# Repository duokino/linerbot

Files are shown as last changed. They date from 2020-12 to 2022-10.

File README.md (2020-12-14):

# LinerBot
Idea asal LinerBot adalah membina sebuah mobile robot mini yang mampu mengesan dan bergerak mengikut garisan.

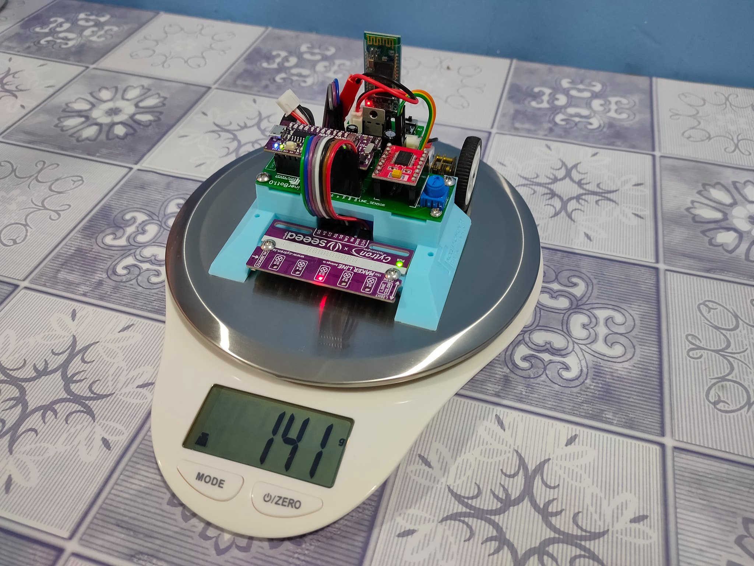
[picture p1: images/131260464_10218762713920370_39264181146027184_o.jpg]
LinerBot


Dalam proses membina LinerBot telah berlaku beberapa proses seperti ujian pendawaian motor, kalibrasi penjajaran roda kanan dan kiri dan beberapa proses lain bagi memastikan LinerBot dapat bergerak secara optimum.

Kesemua proses ini memerlukan komponen tambahan bagi memudahkan proses tersebut. Dari situ terhasil Papan Induk Kawalan LinerBot bagi memudahkan proses tersebut seperti keperluan kepada pengguna Push Button, Potentiometer dan terminal port yang lain yang boleh menambahkan fungsi LinerBot.

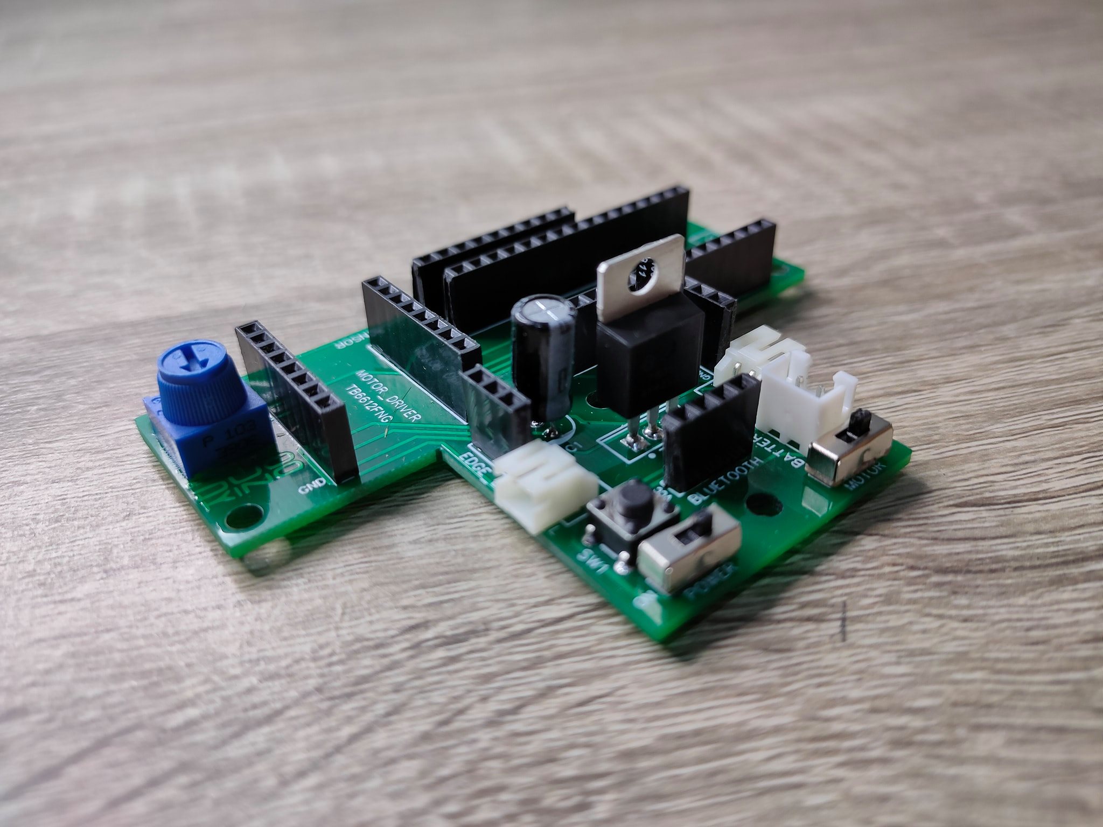
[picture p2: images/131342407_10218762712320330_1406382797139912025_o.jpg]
Additional Input/Output


Papan Induk Kawalan LinerBot ini sedikit sebanyak membantu proses pembelajaran khasnya dalam pembinaan mobile robot daripada asas kepada fungsi tambahan kawalan jarak jauh dan seterusnya fungsi autonomous.

Kawalan jarak jauh boleh menggunakan Bluetooth Module seperti HC-05 atau HC-06 menggunakan terminal Bluetooth yang tersedia pada Papan Induk Kawalan LinerBot.

Mode kawalan jarak jauh juga boleh menggunakan Remote Control seperti jenis Futaba dan yang seangkatan dengannya menggunakan terminal EDGE_L dan EDGE_R sebagai GPIO1 dan GPIO2 signal input. Ini menjadikan Linerbot boleh dikawal dengan alat kawalan radio frekuensi yang lebih advance.

Kesediaan terminal bagi sensor juga membolehkan LinerBot sama ada digunakan untuk robot yang bergerak mengikut garisan atau yang boleh mengelak objek malah boleh juga digunakan sebagai robot sumo.

Kepelbagaian ini semua adalah bergantung pada kreativiti programming yang dibuat yang sememangnya sesuai digunakan untuk tujuan pembelajaran mobile robot atau autonomous robot.

- Buzzer menggunakan D8
- Push Button menggunakan D2 (INPUT_PULLUP)
- Potentiometer/Trimmer menggunakan A0

Bahan untuk membina LinerBot :
  - Chassis (3D Printed main_body.stl)
  - M3 x 6mm self tapping screw

Komponen utama yang perlu dipasang pada Papan Induk Kawalan LinerBot ini adalah :
  - Arduino Nano (penggunaan Maker Nano akan menjadikannya lebih menarik)
    (https://my.cytron.io/p-maker-nano-simplifying-arduino-for-projects?search=maker&description=1)
  - Motor Driver TB6612FNG
    (https://my.cytron.io/p-tb6612fng-dual-channel-1p2a-motor-driver-presoldered-header?search=tb6612&description=1)
  - Metal Micro GearMotor (dicadangkan 6V 600rpm)
    (https://my.cytron.io/p-6v-600rpm-medium-power-dc-micro-metal-gearmotor)
  - LiPo Battery 7.4V
    (https://my.cytron.io/p-lipo-battery-7.4v-450mah)
  - Mini Wheel 34x7mm
    (https://my.cytron.io/p-mini-wheel-34x7mm-for-n20-gear-motor?search=wheel&description=1)

Untuk fungsi Bluetooth RC memerlukan komponen tambahan Bluetooth Module sama ada :
  - HC-05 atau HC-06

Untuk fungsi robot mengikut garisan :
  - Maker Line
    (https://my.cytron.io/p-maker-line-simplifying-line-sensor-for-beginner?search=maker%20line&description=1)
  atau
  - LSS05
    (https://my.cytron.io/p-auto-calibrating-line-sensor?search=lss05&description=1)
  tambahan
  - Maker Reflect
    (https://my.cytron.io/p-maker-reflect-simplifying-ir-reflectance-sensor-for-beginner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)

Untuk fungsi robot sumo atau robot pengelak objek dicadangkan menggunakan :
  - Maker Object
    (https://my.cytron.io/p-maker-object-simplifying-object-sensor-for-beginner?search=maker%20object&description=1)
  atau
  - HC-SR04 Ultrasonic Sensor
    (https://my.cytron.io/p-5v-hc-sr04-ultrasonic-sensor?search=ultrasonic&description=1)

Untuk fungsi RC Radio Frekuensi boleh menggunakan FlySky 3 Channels RC Radio Transmitter and Receiver dan yang seangkatan dengannya
(https://my.cytron.io/p-flysky-3-channels-rc-radio-transmitter-and-receiver)

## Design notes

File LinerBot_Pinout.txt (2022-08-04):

//*******PINOUT*******\\

Trimmer Pot	= A0

Analog Input	= A1
		= A2
		= A3
		= A4
		= A5

CAL		= 13

EDGE_L		= A6
EDGE_R		= A7

BUZZER		= 8

PushButton	= 2

PWMA		= 3
AIN1		= 5
AIN2		= 4

PWMB		= 10
BIN1		= 12
BIN2		= 11

Bluetooth_RX	= 0 (TX)
Bluetooth_TX	= 1 (RX)

//***Pin Not In Use***\\
	6 (PWM)
	7
	9 (PWM)

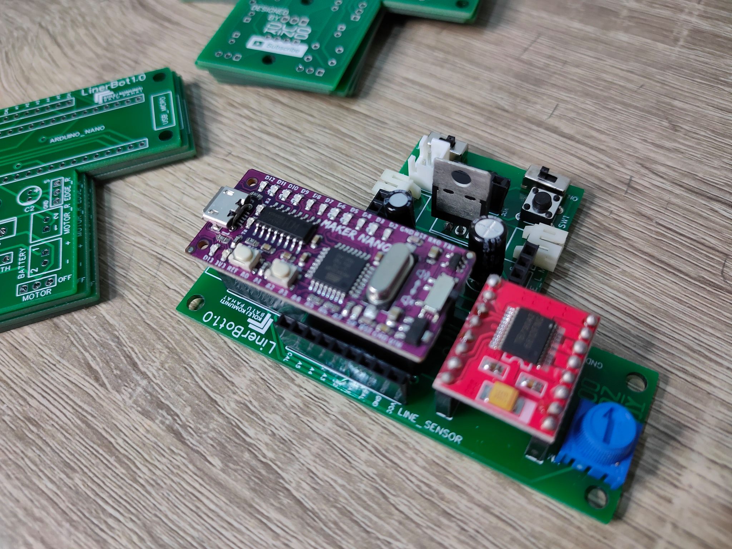
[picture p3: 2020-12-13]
images/129722210_10218738056543951_4481146567513950137_o.jpg

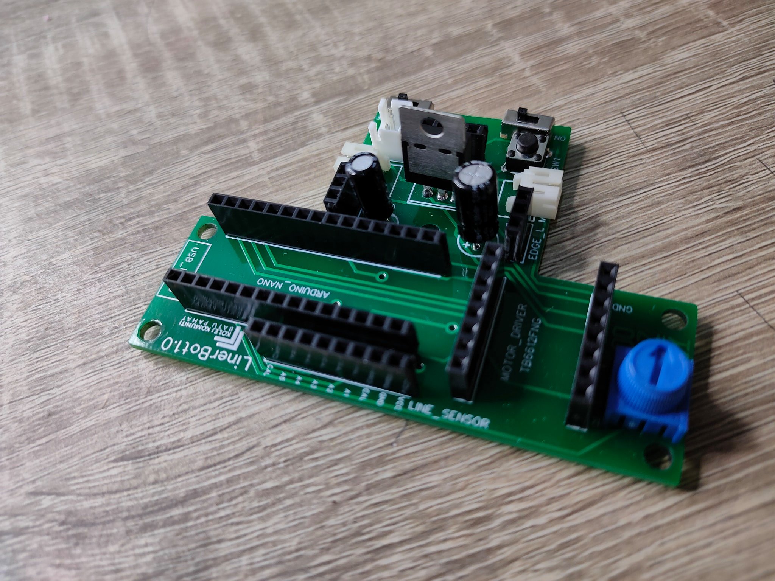
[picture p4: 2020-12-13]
images/130556127_10218762712080324_7497710717040345730_o.jpg

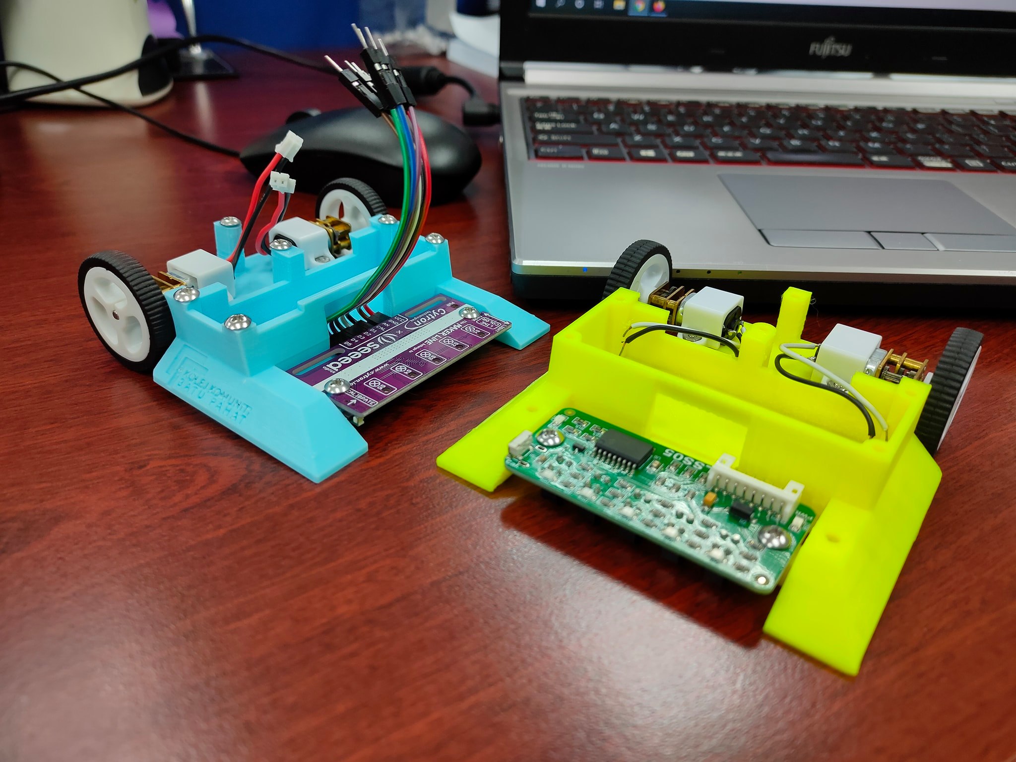
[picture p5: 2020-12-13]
images/127145666_10218675507100254_2346838579680617571_o.jpg

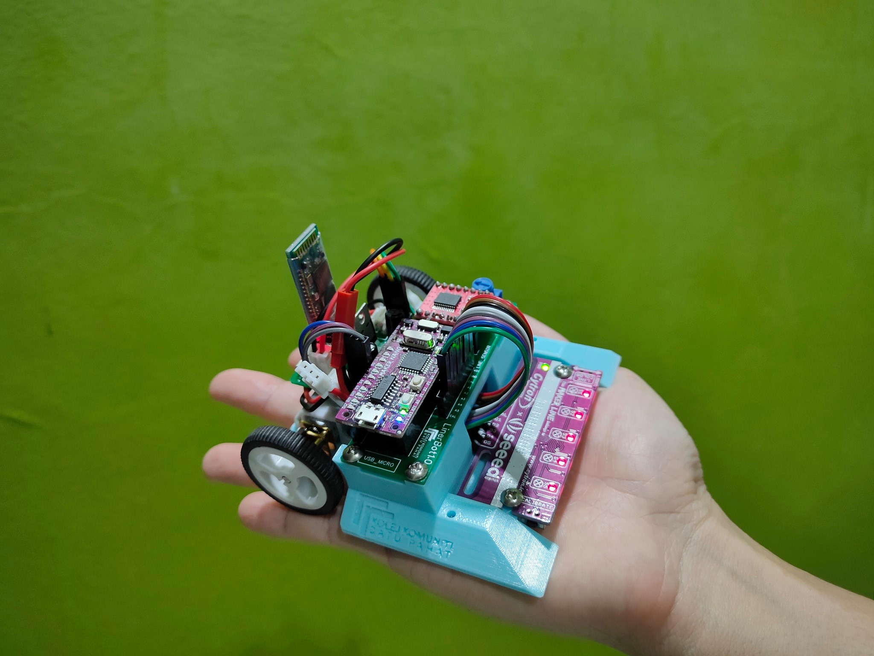
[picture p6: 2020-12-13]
images/130770970_10218762714600387_8051663689108889609_o.jpg

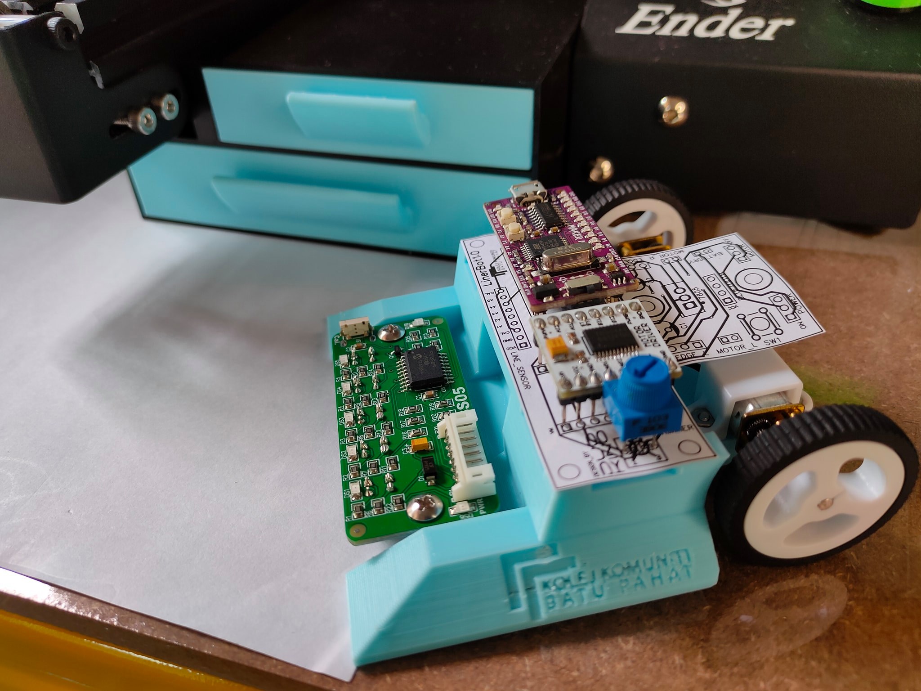
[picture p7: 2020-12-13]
images/128410288_10218690125145696_120835944138036377_o.jpg

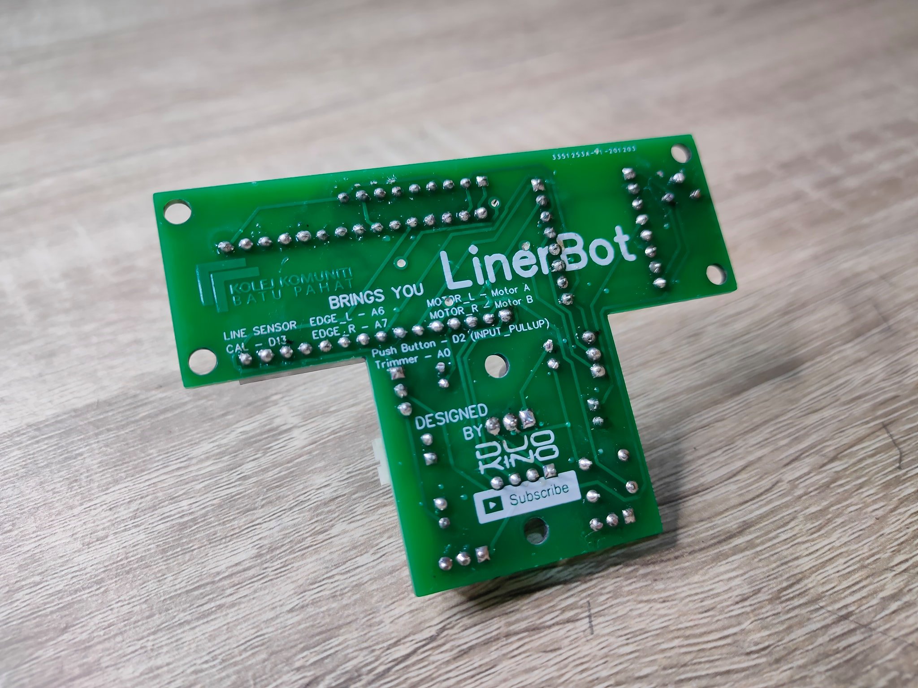
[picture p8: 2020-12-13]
images/131317444_10218762712720340_863234847753100694_o.jpg

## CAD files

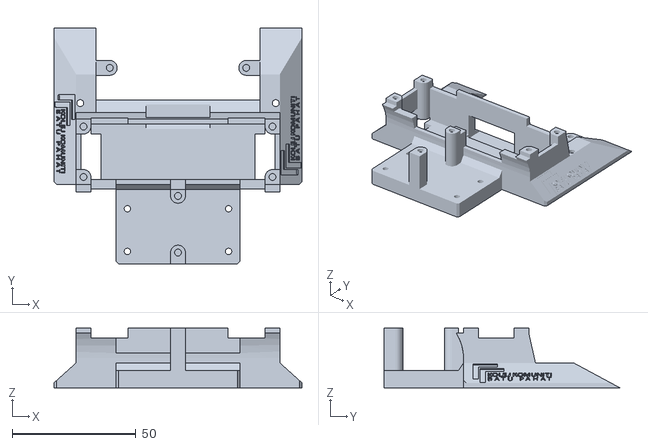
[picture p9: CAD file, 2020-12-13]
STL/main_body.stl
100.0 x 95.0 x 24.0

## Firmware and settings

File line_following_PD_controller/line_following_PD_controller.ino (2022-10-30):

/*
 This is for Line Follower
 using PID Controller for LinerBot
 with Auto Calibrate Sensor
 Maker Line from cytron for line sensor
 by Duokino
 */
 
//Pin declaration for TB6612FNG

//Motor Right
#define PWMB 10 //Speed control
#define BIN1 12 //Direction
#define BIN2 11 //Direction

//Motor Left
#define PWMA 3 //Speed control
#define AIN1 5 //Direction
#define AIN2 4 //Direction

  //sensor
  int VR = A0;
  
  int S1 = 0;
  int S2 = 0;
  int S3 = 0;
  int S4 = 0;
  int S5 = 0;

  int sensorValue;
  int position;

int motorSpeed;
int error;

int mode = 0;

    int BaseSpeed = 160;
    float Kp = 0.08; 
    float Kd = 4.8; 
    float Ki = 0.000; 
    int integral = 0;
    int lastError = 0; 
    int MotorA_Speed = 0; 
    int MotorB_Speed = 0; 
    int offset = 2000;

void setup() {

  pinMode (VR, INPUT);
  
  pinMode (A1, INPUT);
  pinMode (A2, INPUT);
  pinMode (A3, INPUT);
  pinMode (A4, INPUT);
  pinMode (A5, INPUT);

  //Motor Driver Pin Setup
  pinMode (PWMB,OUTPUT);
  pinMode (BIN1,OUTPUT);
  pinMode (BIN2,OUTPUT);
  pinMode (PWMA,OUTPUT);
  pinMode (AIN1,OUTPUT);
  pinMode (AIN2,OUTPUT);

  Serial.begin (9600);

  melody();

  while (mode < 1) button();
  
  delay(100);

}

void loop() {

  //read sensor
  S1 = digitalRead(A1);
  S2 = digitalRead(A2);
  S3 = digitalRead(A3);
  S4 = digitalRead(A4);
  S5 = digitalRead(A5);
  
  if (S1 == 0 && S2 == 0 && S3 == 1 && S4 == 0 && S5 == 0) sensorValue = 2000;
  else if (S1 == 1 && S2 == 0 && S3 == 0 && S4 == 0 && S5 == 0) sensorValue = 3500;
  else if (S1 == 0 && S2 == 1 && S3 == 0 && S4 == 0 && S5 == 0) sensorValue = 2500;
  else if (S1 == 0 && S2 == 0 && S3 == 0 && S4 == 1 && S5 == 0) sensorValue = 1500;
  else if (S1 == 0 && S2 == 0 && S3 == 0 && S4 == 0 && S5 == 1) sensorValue = 500;

  else if (S1 == 1 && S2 == 1 && S3 == 0 && S4 == 0 && S5 == 0) sensorValue = 2600;
  else if (S1 == 0 && S2 == 1 && S3 == 1 && S4 == 0 && S5 == 0) sensorValue = 2050;
  else if (S1 == 0 && S2 == 0 && S3 == 1 && S4 == 1 && S5 == 0) sensorValue = 1950;
  else if (S1 == 0 && S2 == 0 && S3 == 0 && S4 == 1 && S5 == 1) sensorValue = 1400;

  else if (S1 == 0 && S2 == 1 && S3 == 1 && S4 == 1 && S5 == 0) sensorValue = 2000;
  else if (S1 == 1 && S2 == 1 && S3 == 1 && S4 == 0 && S5 == 0) sensorValue = 2500;
  else if (S1 == 0 && S2 == 0 && S3 == 1 && S4 == 1 && S5 == 1) sensorValue = 1500;

  if (sensorValue <= 1500){
    if (S1 == 0 && S2 == 0 && S3 == 0 && S4 == 0 && S5 == 0) sensorValue = 0;
    }

  else if (sensorValue >= 2500){
    if (S1 == 0 && S2 == 0 && S3 == 0 && S4 == 0 && S5 == 0) sensorValue = 4000;
    }

  position = sensorValue - offset;

  //variable to be adjust
  //Kp = analogRead(VR);
  //Kp = Kp/700;
  //Serial.print("Kp = ");
  //Serial.println(Kp);

  //Kd = analogRead(VR);
  //Kd = Kd/50
  //Serial.print("Kd = ");
  //Serial.println(Kd);

  //PID calculation  

  error = position;
      
  motorSpeed = Kp * error + Kd * (error - lastError) + Ki * integral; 
  lastError = error;

  //Motor output

  MotorA_Speed = BaseSpeed - motorSpeed ; 
  MotorB_Speed = BaseSpeed + motorSpeed ; 
  MotorA_Speed = constrain(MotorA_Speed, 0, 255); 
  MotorB_Speed = constrain(MotorB_Speed, 0, 255);

  digitalWrite(AIN2, HIGH); 
  digitalWrite(AIN1, LOW); 
  analogWrite(PWMA, MotorA_Speed);
       
  digitalWrite(BIN2, HIGH); 
  digitalWrite(BIN1, LOW); 
  analogWrite(PWMB, MotorB_Speed);
/*
  Serial.print("error = ");
  Serial.print(error);
  Serial.print("     Left = ");
  Serial.print(MotorA_Speed);
  Serial.print("     Right = ");
  Serial.println(MotorB_Speed);
*/
}

void melody(){

  #define NOTE_B5   988
  #define NOTE_G5   784
  #define NOTE_A5   880
  #define NOTE_DS6  1245
  #define NOTE_CS6   1109
  
  #define BUZZER 8
  
  int melody[] = {NOTE_B5, 0, NOTE_G5, NOTE_A5, NOTE_B5, 0, NOTE_G5, NOTE_A5, NOTE_B5, 0, NOTE_B5, NOTE_B5, NOTE_DS6, NOTE_DS6, NOTE_B5, NOTE_B5, NOTE_CS6};
  int noteDurations[] = {4, 16, 8, 4, 4, 16, 8, 4, 4, 8, 4, 8, 4, 8, 4, 8, 2};
  
    for (int thisNote = 0; thisNote < 17; thisNote++){
      int noteDuration = 1000 / noteDurations[thisNote];
      tone(BUZZER, melody[thisNote], noteDuration);
      int pauseBetweenNotes = noteDuration * 1.30;
      delay(pauseBetweenNotes);
      noTone(BUZZER);
    }
}

void button() {
  #define NOTE_C5 523
  #define NOTE_G5 784

  #define BUTTON 2
  #define BUZZER 8

  boolean buttonPressed = false;

  pinMode(BUTTON, INPUT_PULLUP);
  
    if (digitalRead(BUTTON) == LOW &&
        buttonPressed == false) {
      buttonPressed = true;
      mode++;
      if (mode == 1) {
        tone(BUZZER, NOTE_C5, 100);
        delay(100);
        tone(BUZZER, NOTE_G5, 100);
        delay(100);
        noTone(BUZZER);
      }
      else if (mode == 2) {
        tone(BUZZER, NOTE_G5, 100);
        delay(100);
        tone(BUZZER, NOTE_C5, 100);
        delay(100);
        noTone(BUZZER);
      }
    }

  if (buttonPressed == true) {
  buttonPressed = false;
  }
}

//*************best value*************\\
//  Kp=0.08 Kd=4.6 Speed=138 Time=4.54s
//  Kp=0.08 Kd=4.8 Speed=145 Time=4.44s
//  Kp=0.08 Kd=4.8 Speed=160 Time=5.24s LinerBot Purple
//  Kp=0.08 Kd=4.8 Speed=160 Time=4.48  Slick
//  Kp=0.06 Kd=4.8 Speed=150 Time=4.56  Slick
//  Kp=0.06 Kd=4.8 Speed=160 Time=4.52  Slick
//  Kp=0.08 Kd=4.8 Speed=180 Time=3.55  Slick
//  Kp=0.09 Kd=4.8 Speed=210 Time=3.49  Slick
//  Kp=0.08 Kd=4.8 Speed=200 Time=3.22  Slick

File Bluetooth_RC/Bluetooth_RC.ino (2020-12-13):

/*
 This is for Bluetooth Module RC
 for LinerBot
 Install Arduino Bluetooth RC Car
 from PlayStore in Android phone
 by Duokino
 */

char t;

//Motor Right
int PWMB = 10; //Speed control
int BIN1 = 12; //Direction
int BIN2 = 11; //Direction

//Motor Left
int PWMA = 3; //Speed control
int AIN1 = 5; //Direction
int AIN2 = 4; //Direction

//Slipp  percentage between Right Motor and Left Motor
int slipp = 6;     //use align_motor_speed.ino to find this value


void setup() {

  //motor setup
  pinMode(PWMA, OUTPUT);
  pinMode(AIN1, OUTPUT);
  pinMode(AIN2, OUTPUT);
  
  pinMode(PWMB, OUTPUT);
  pinMode(BIN1, OUTPUT);
  pinMode(BIN2, OUTPUT);

  //sensor setup using Maker Line
  pinMode(13, OUTPUT);
  digitalWrite(13, HIGH);
  
  Serial.begin(9600);
  
  melody();

}

void loop() {

  int VR, motorspeed;
  int rightmotor, leftmotor;
  
  VR = analogRead(A0);
  motorspeed = map(VR, 0, 1023, 0, 255);
  
  rightmotor = motorspeed;
  leftmotor = rightmotor - (slipp * 0.003 * motorspeed);
  
  if(Serial.available()){
    t = Serial.read();
    Serial.println(t);
  }
   
  if(t == 'F'){            //move forward
    forward(rightmotor, leftmotor);
  }
   
  else if(t == 'B'){      //move reverse
    backward(rightmotor, leftmotor);
  }
   
  else if(t == 'L'){      //turn right
    left(motorspeed);
  }
   
  else if(t == 'R'){      //turn left
    right(motorspeed);
  }
  
  else if(t == 'S'){      //STOP (all motors stop)
    still();
  }
  //delay(100);

}

void forward(int rightmotor, int leftmotor){

  digitalWrite(BIN1, LOW);
  digitalWrite(BIN2, HIGH);
  analogWrite(PWMB, rightmotor);
  
  digitalWrite(AIN1, LOW);
  digitalWrite(AIN2, HIGH);
  analogWrite(PWMA, leftmotor);

}

void backward(int rightmotor, int leftmotor){

  digitalWrite(BIN1, HIGH);
  digitalWrite(BIN2, LOW);
  analogWrite(PWMB, rightmotor);
  
  digitalWrite(AIN1, HIGH);
  digitalWrite(AIN2, LOW);
  analogWrite(PWMA, leftmotor);

}

void right(int motorspeed){

  digitalWrite(BIN1, HIGH);
  digitalWrite(BIN2, LOW);
  analogWrite(PWMB, 0);
  
  digitalWrite(AIN1, LOW);
  digitalWrite(AIN2, HIGH);
  analogWrite(PWMA, motorspeed);

}

void left(int motorspeed){

  digitalWrite(BIN1, LOW);
  digitalWrite(BIN2, HIGH);
  analogWrite(PWMB, motorspeed);
  
  digitalWrite(AIN1, HIGH);
  digitalWrite(AIN2, LOW);
  analogWrite(PWMA, 0);

}

void still(){

  digitalWrite(BIN1, LOW);
  digitalWrite(BIN2, LOW);
  analogWrite(PWMB, 0);
  
  digitalWrite(AIN1, LOW);
  digitalWrite(AIN2, LOW);
  analogWrite(PWMA, 0);

}

void melody(){

  #define NOTE_B5   988
  #define NOTE_G5   784
  #define NOTE_A5   880
  #define NOTE_DS6  1245
  #define NOTE_CS6   1109
  
  #define BUZZER 8
  
  int melody[] = {NOTE_B5, 0, NOTE_G5, NOTE_A5, NOTE_B5, 0, NOTE_G5, NOTE_A5, NOTE_B5, 0, NOTE_B5, NOTE_B5, NOTE_DS6, NOTE_DS6, NOTE_B5, NOTE_B5, NOTE_CS6};
  int noteDurations[] = {4, 16, 8, 4, 4, 16, 8, 4, 4, 8, 4, 8, 4, 8, 4, 8, 2};
  
    for (int thisNote = 0; thisNote < 17; thisNote++){
      int noteDuration = 1000 / noteDurations[thisNote];
      tone(BUZZER, melody[thisNote], noteDuration);
      int pauseBetweenNotes = noteDuration * 1.30;
      delay(pauseBetweenNotes);
      noTone(BUZZER);
    }
}
